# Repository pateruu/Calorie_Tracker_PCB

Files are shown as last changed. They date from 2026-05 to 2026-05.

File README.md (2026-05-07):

# Calorie Tracker PCB

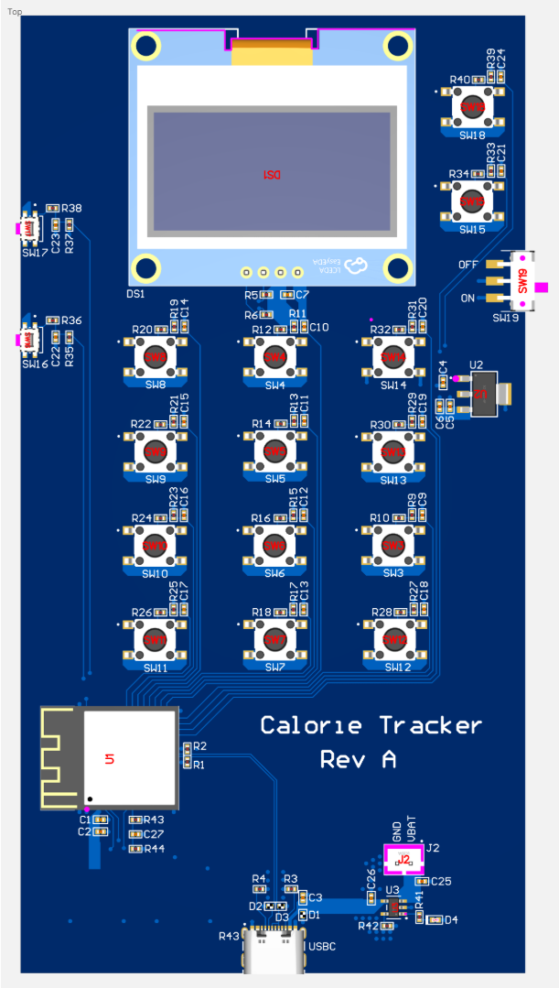
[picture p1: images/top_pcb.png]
Top PCB


A compact embedded handheld device built around an **ESP32-S3**, featuring an **OLED display**, **button-based numeric input**, **USB-C power/programming**, **battery charging**, and onboard **3.3V regulation** to track cumulative calorie intake.

This project focuses on the **hardware design** of a portable calorie tracker, including schematic capture, PCB layout, power architecture, button input circuitry, and manufacturing files. Firmware bring-up is being developed separately using an ESP32-based prototype platform before full hardware fabrication.

---

## Overview

The goal of this project was to design a custom handheld PCB that could serve as a dedicated calorie tracking device. The board is centered around an **ESP32-S3** and uses a **OLED display** for UI output, along with a set of **physical buttons** for entering values and navigating the interface.

The design includes:

- **ESP32-S3** microcontroller
- **OLED display** interface
- **button-based input** with debounce filtering
- **USB-C** for power and programming
- **battery charging / battery connector**
- **VBAT to 3.3V regulation**
- **persistent storage support through the MCU**
- custom schematic, PCB layout, BOM, pick-and-place, and fabrication files

---

## Key Features

- Custom **ESP32-S3 handheld PCB**
- **OLED display** for calorie total and UI feedback
- **Button-based numeric input** and menu navigation
- **USB-C power and programming**
- **Battery charging and power-path support**
- Onboard **3.3V regulator**
- Hardware debounce on user input buttons
- Organized design files for manufacturing and documentation

---

## Hardware Highlights

### Main Components
- **ESP32-S3** microcontroller
- **1.54" OLED display** interface
- **USB-C connector** with protection and CC resistors
- **Battery charging IC**
- **VBAT to 3.3V regulator**
- Tactile buttons for:
  - numeric entry
  - menu/navigation
  - reset
  - boot/programming access

### Design Considerations
- Routed dedicated **power rails** for **VBAT**, **VSYS**, and **+3V3_REG**
- Added local **decoupling capacitors** near critical ICs
- Implemented **button debounce/filter networks**
- Used **ground stitching vias** in USB and power areas
- Kept USB protection and power components grouped tightly near the connector

---

## Current Status

### Completed
- Schematic capture
- PCB placement and routing
- Power architecture
- USB-C and protection layout
- OLED and button interface design
- BOM / CPL / manufacturing file generation
- LTspice simulation for button debounce validation

### In Progress
- Firmware prototyping on ESP32 development hardware
- UI / input logic validation
- Pre-fabrication review and cleanup

### Planned
- Fabrication / assembly
- Bring-up and validation on final custom board
- Enclosure integration
- Final user interface refinement

---

## Repository Structure

```text
Calorie_Tracker_PCB/
├── docs/
├── firmware/
├── hardware/
│   ├── 3d_model/
│   ├── bom/
│   ├── drc/
│   ├── gerber/
│   ├── nc_drill/
│   ├── pcb/
│   ├── pick_place/
│   └── schematic/
├── images/
├── simulations/
│   └── ltspice/
├── LICENSE
└── README.md

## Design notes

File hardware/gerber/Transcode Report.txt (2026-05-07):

   ---- Transcoding 'C:\Users\Public\Documents\Altium\Calorie Tracker\Project Outputs for Calorie Tracker\Gerber\Calorie Tracker PCB.G1' ----   Wed May  6 06:54:53 2026

D56   --> D100
D57   --> D101
D64   --> D102
D65   --> D103
D67   --> D104
D68   --> D105
-----------------------------------------------------------------

   ---- Transcoding 'C:\Users\Public\Documents\Altium\Calorie Tracker\Project Outputs for Calorie Tracker\Gerber\Calorie Tracker PCB.GBL' ----   Wed May  6 06:54:53 2026

D25   --> D106
D56   --> D107
D57   --> D108
D64   --> D109
D65   --> D110
D66   --> D111
D67   --> D112
D68   --> D113
-----------------------------------------------------------------

   ---- Transcoding 'C:\Users\Public\Documents\Altium\Calorie Tracker\Project Outputs for Calorie Tracker\Gerber\Calorie Tracker PCB.GBP' ----   Wed May  6 06:54:53 2026

D25   --> D114
-----------------------------------------------------------------

   ---- Transcoding 'C:\Users\Public\Documents\Altium\Calorie Tracker\Project Outputs for Calorie Tracker\Gerber\Calorie Tracker PCB.GBS' ----   Wed May  6 06:54:53 2026

D53   --> D115
D54   --> D116
D55   --> D117
D56   --> D118
D57   --> D119
D58   --> D120
D59   --> D121
-----------------------------------------------------------------

   ---- Transcoding 'C:\Users\Public\Documents\Altium\Calorie Tracker\Project Outputs for Calorie Tracker\Gerber\Calorie Tracker PCB.GP1' ----   Wed May  6 06:54:53 2026

D73   --> D122
D74   --> D123
D75   --> D124
D76   --> D125
D77   --> D126
D78   --> D127
-----------------------------------------------------------------

   ---- Transcoding 'C:\Users\Public\Documents\Altium\Calorie Tracker\Project Outputs for Calorie Tracker\Gerber\Calorie Tracker PCB.GTL' ----   Wed May  6 06:54:53 2026

D18   --> D128
D19   --> D129
D20   --> D130
D22   --> D131
D23   --> D132
D24   --> D133
D25   --> D134
D27   --> D135
D28   --> D136
D29   --> D137
D30   --> D138
D31   --> D139
D32   --> D140
D33   --> D141
D34   --> D142
D35   --> D143
D36   --> D144
D56   --> D145
D57   --> D146
D64   --> D147
D65   --> D148
D66   --> D149
D67   --> D150
D68   --> D151
-----------------------------------------------------------------

   ---- Transcoding 'C:\Users\Public\Documents\Altium\Calorie Tracker\Project Outputs for Calorie Tracker\Gerber\Calorie Tracker PCB.GTP' ----   Wed May  6 06:54:53 2026

D18   --> D152
D19   --> D153
D20   --> D154
D22   --> D155
D23   --> D156
D24   --> D157
D25   --> D158
D27   --> D159
D28   --> D160
D29   --> D161
D30   --> D162
D31   --> D163
D32   --> D164
D33   --> D165
D34   --> D166
D35   --> D167
D36   --> D168
-----------------------------------------------------------------

   ---- Transcoding 'C:\Users\Public\Documents\Altium\Calorie Tracker\Project Outputs for Calorie Tracker\Gerber\Calorie Tracker PCB.GTS' ----   Wed May  6 06:54:53 2026

D20   --> D169
D28   --> D170
D31   --> D171
D32   --> D172
D38   --> D173
D39   --> D174
D40   --> D175
D41   --> D176
D42   --> D177
D43   --> D178
D45   --> D179
D46   --> D180
D47   --> D181
D48   --> D182
D49   --> D183
D50   --> D184
D51   --> D185
D52   --> D186
D53   --> D187
D54   --> D188
D55   --> D189
D56   --> D190
D57   --> D191
D58   --> D192
D59   --> D193
-----------------------------------------------------------------

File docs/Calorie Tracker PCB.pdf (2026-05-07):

# Calorie Tracker PCB Project Plan

Planning document for turning my current ESP32-S3 board into a compact handheld embedded device.
Project | Battery-powered handheld calorie tracker with OLED display, numeric button input, persistent storage, and custom PCB.
Goal | Reuse my ESP32-S3 design, remove unnecessary dev-board style circuitry, and build a clean enclosure-ready PCB.

## 1. Project Summary

My plan is to take the ESP32-S3 schematic I already built and reduce it into a focused product-style board instead of a general-purpose development board. The final device will let a user enter calorie values with buttons, view the running total on a small OLED screen, and keep the saved total even after power is removed.

## 2. Recommended Project Scope

- Use an ESP32-S3 module as the main controller.
- Use a 128×64 I2C OLED for the display.
- Provide button input for digits 0–9 and at least Enter / Clear / Reset.
- Store the running calorie total in non-volatile memory so data survives power-off.
- Keep one USB-C port for programming and wired power.
- Use a 3.3 V power rail for the ESP32-S3 and display.
- Lay out the board for a compact handheld enclosure.

## 3. High-Level System Architecture

Input | Controller | Output / Storage | Power
Buttons or keypad 0–9, Enter, Reset | ESP32-S3-MINI | 128×64 OLED NVS or external FRAM / EEPROM | USB-C 5 V input 3.3 V regulator LiPo battery

## 4. Components Needed (High-Level BOM)

Block | Main Item | Notes | Need?
MCU | ESP32-S3-MINI module | Main processor; reuse current design base | Yes
Display | 128×64 OLED, I2C | Small display for totals and menus | Yes
User input | Tactile buttons / keypad | Digits 0–9 plus Enter, Clear | Yes
Reset / boot | Reset and boot buttons | Keep for programming and recovery | Yes
USB | Single USB-C connector | Use for power and programming | Yes
Power | 3.3 V regulator | Convert 5 V or battery input to 3.3 V | Yes
Protection | ESD / decoupling / bulk caps | Keep standard USB and power support parts | Yes
Storage | ESP32 NVS or external FRAM | NVS is simplest; FRAM is stronger on hardware story | Yes
Battery option | LiPo connector + charger or AAA | Recommended over coin cell if | Optional

holder | portable power is needed

## 7. New Hardware Blocks To Add

- OLED interface wiring: VCC, GND, SDA, SCL, and any required pull-ups if not already present.
- Button network: either individual GPIO buttons or a keypad matrix to reduce pin count.
- Persistent storage choice: use ESP32 non-volatile storage first; optionally add external FRAM.
- Optional battery block: battery connector, charger IC, power-path handling, and battery sense divider.
- Optional on/off switch or load switch for a more product-like feel.

## 8. Firmware Plan

Feature | Planned behavior
Startup | On boot, load saved total from non-volatile memory and show it on the OLED.
Input | User enters a number with buttons 0–9; Enter confirms and adds the value.
Clear / edit | Allow Clear or Backspace behavior before confirming entry.
Reset total | Dedicated reset action sets the total back to zero after confirmation.
Persistence | Save the updated total after each confirmed entry so power loss does not erase data.
Low power | Optional deep-sleep mode with wake on button press.

## 9. PCB Layout Notes

- Place the OLED and main input buttons to support a handheld front-face layout.
- Keep the ESP32-S3 antenna edge clear: no copper pour, metal, battery, or display hardware in the keep-out area.
- Keep the power path short and clean from USB-C input to regulator to 3.3 V rail.
- Place decoupling capacitors close to the ESP32-S3 power pins and regulator pins.
- Add test points for 5 V, 3.3 V, GND, reset, and any important debug lines.
Mechanical planning matters here. The board should be laid out with the enclosure in mind from the beginning so the switch, OLED opening, and button positions look intentional.

## 11. Best Stretch Goals

1. Battery support: Add rechargeable battery charging and monitoring.
2. Low-power mode: Implement deep sleep and measure active vs. sleep current.
3. Keypad matrix: Reduce GPIO usage and clean up the front panel.
4. Enclosure: Add a 3D-printed case and show the assembled device.

## 13. Suggested Build Phases

5. Phase 1 — Schematic cleanup: Remove extra dev-board blocks and keep only the final device architecture.
6. Phase 2 — Peripheral addition: Add OLED, buttons, storage choice, and optional battery block.

7. Phase 3 — Firmware bring-up: Display startup screen, read buttons, and save/load totals.
8. Phase 4 — PCB layout: Route a compact board with test points and antenna keep-out respected.
9. Phase 5 — Prototype validation: Flash firmware, verify power rail stability, and test storage retention.
10. Phase 6 — Product polish: Add enclosure, measure current, and capture final build photos.

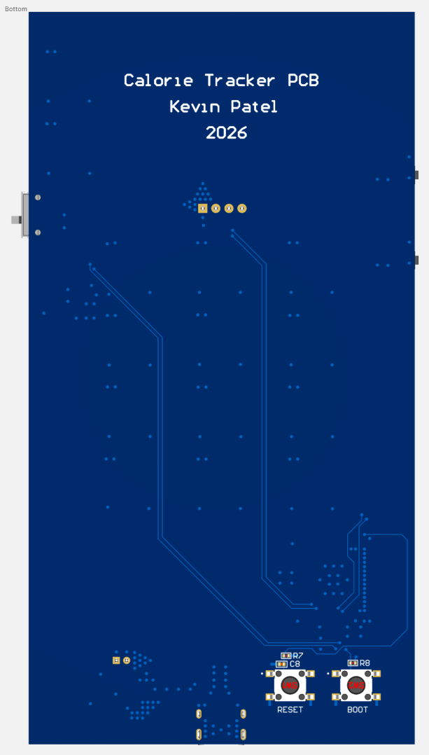
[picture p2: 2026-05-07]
images/bottom_pcb.png

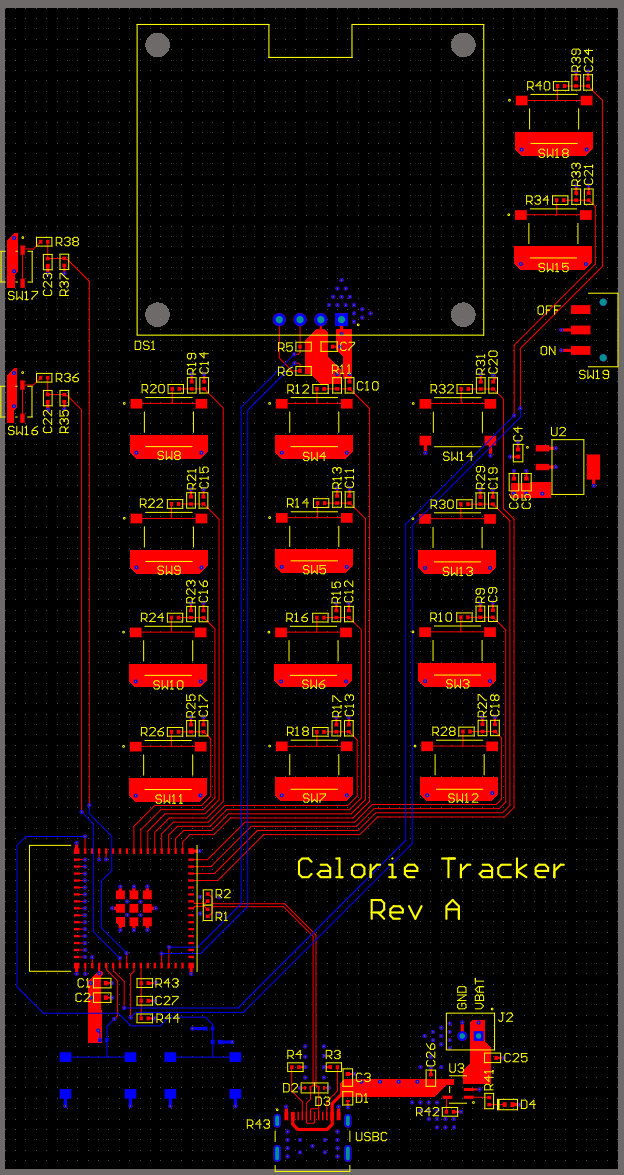
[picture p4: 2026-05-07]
images/top_and_bottom_pcb_altium.png

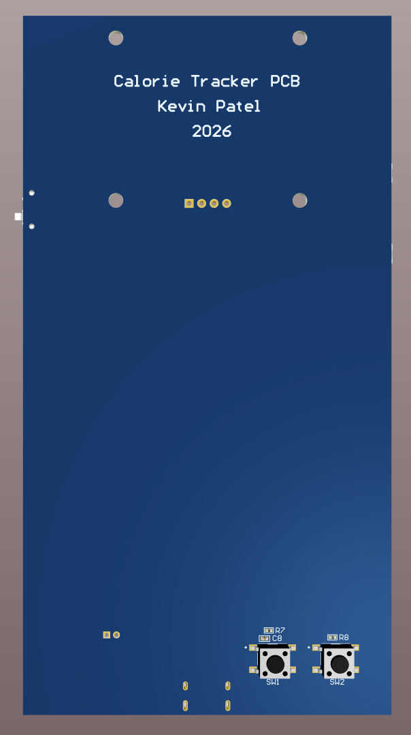
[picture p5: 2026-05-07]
images/bottom_pcb_altium.png

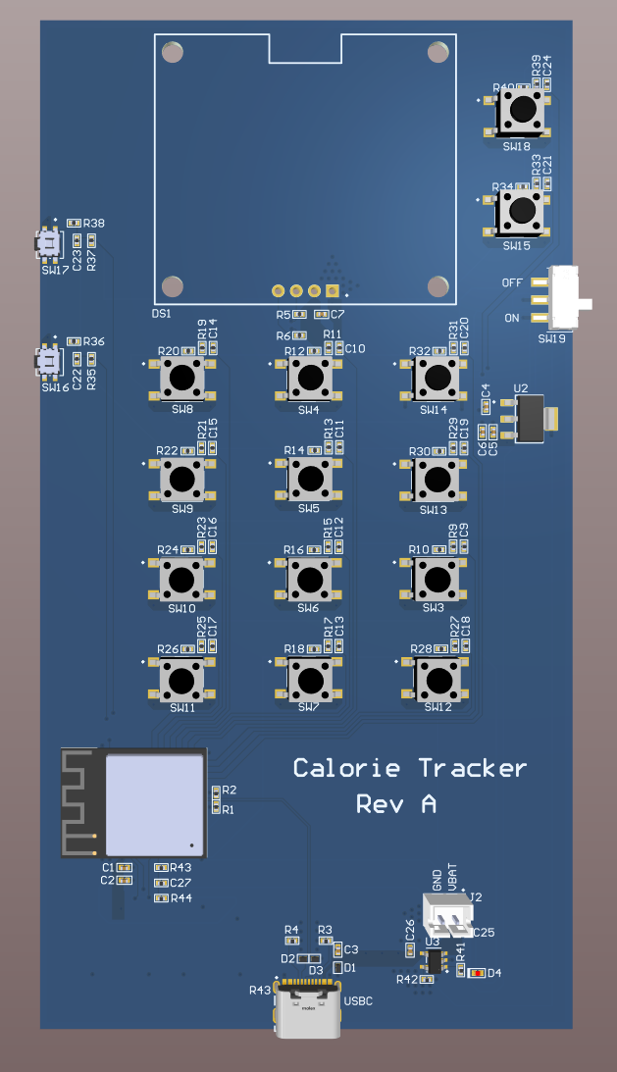
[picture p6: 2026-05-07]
images/top_pcb_altium.png

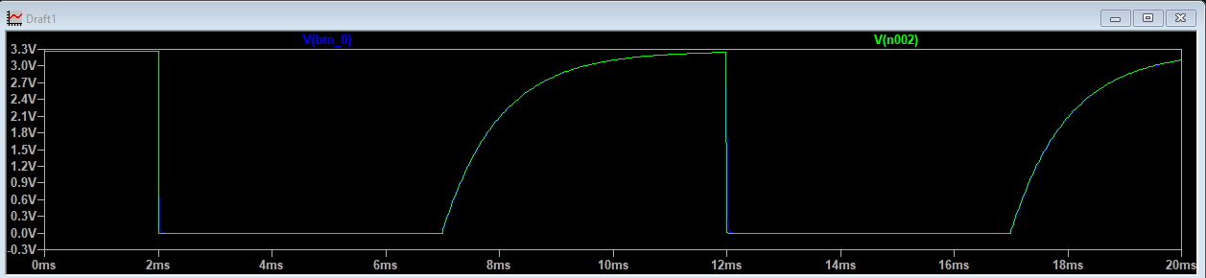
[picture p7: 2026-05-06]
simulations/ltspice/btn0_ltspice_plot.png

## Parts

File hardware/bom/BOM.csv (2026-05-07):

Name | Description | Designator | Footprint | LibRef | Quantity | LCSC Part Number | Manufacturer | Manufacturer Part Number | Supplier | Supplier Part Number
10uF, 10V | CAP CER 10UF 10V X5R 0402 | C1, C5, C6 | CAPC1005X65N | CL05A106MP6NUN8 | 3 | C3902158 | Samsung Electro-Mechanics | CL05A106MP6NUN8 | DigiKey | 1276-CL05A106MP6NUN8CT-ND
100nF, 50V | 0.1 µF ±10% 50V Ceramic Capacitor X7R 0402 (1005 Metric) | C2, C3 | CAPC1005X65N | CL05B104KB5NNNC | 2 | C960916 | Samsung Electro-Mechanics | CL05B104KB5NNNC | DigiKey | 1276-CL05B104KB5NNNCCT-ND
4u7, 16V | CAP CER 4.7UF 16V X5R 0402 | C4 | CAPC1005X65N | CL05A475MO5NUNC | 1 | C318563 | Samsung Electro-Mechanics | CL05A475MO5NUNC | DigiKey | 1276-6836-1-ND
0.1uF, 25V | CAP CER 0.1UF 25V X5R 0402 | C7 | 0402 Capacitor Footprint | CL05A104KA5NNNC | 1 | C100072 | Samsung Electro-Mechanics | CL05A104KA5NNNC | DigiKey | 1276-1043-1-ND
1uF, 35V | 1 µF ±10% 35V Ceramic Capacitor X5R 0402 (1005 Metric) | C8 | CAPC1005X65N | CL05A105KL5NRNC | 1 | C307413 | Samsung Electro-Mechanics | CL05A105KL5NRNC | DigiKey | 1276-6796-1-ND
100nF, 16V | CAP CER 0.1UF 16V X7R 0402 | C9, C10, C11, C12, C13, C14, C15, C16, C17, C18, C19, C20, C21, C22, C23, C24, C27 | 0402 Resistor Footprint | CC0402JRX7R7BB104 | 17 | C541464 | Yageo Group | CC0402JRX7R7BB104 | DigiKey | 311-1676-1-ND
4.7uF, 10V | CAP CER 4.7UF 10V X5R 0402 | C25, C26 | 0402 Capacitor Footprint | CL05A475MP5NRNC | 2 | C23733 | Samsung Electro-Mechanics | CL05A475MP5NRNC | DigiKey | 1276-1482-1-ND
AQ3045-01ETG | TVS DIODE 5.3VWM 12VC SOD882 | D1, D2, D3 | SOD882 | AQ3045-01ETG | 3 | C3710326 | Littelfuse | AQ3045-01ETG | DigiKey | F9321CT-ND
RED | LED RED 0402 SMD | D4 | LED0402R | VLMS1500-GS08 | 1 | C511370 | Vishay | VLMS1500-GS08 | DigiKey | VLMS1500-GS08CT-ND
HS154L03W2C01 | 1.54 128x64 SSD1309 chip I2C LCD, OLED, Graphic RoHS | DS1 | HS154L03W2C01 | HS154L03W2C01 | 1 | C7465999 | HS | HS154L03W2C01 | LCSC | HS154L03W2C01
217179-0001 | CONN RCP USB2.0 TYP C 24P SMD RA | J1 | FP-2171790001-MFG | 217179-0001 | 1 | C3197684 | Molex | 217179-0001 | DigiKey | 900-2171790001CT-ND
HDR_1X2_2MM | CONN HEADER VERT 2POS 2MM | J2 | B2B-PH-K-S | B2B-PH-K-S | 1 | C131337 | JST | B2B-PH-K-S | DigiKey | 455-1704-ND
22R | RES 22 OHM 1% 1/16W 0402 | R1, R2 | 0402 Resistor Footprint | RC0402FR-0722RL | 2 | C114765 | Yageo Group | RC0402FR-0722RL | DigiKey | 311-22.0LRCT-ND
5K1 | RES SMD 5.1K OHM 1% 1/16W 0402 | R3, R4 | RESC1005X37N | AC0402FR-075K1L | 2 | C144745 | Yageo Group | AC0402FR-075K1L | DigiKey | YAG3503CT-ND
4K7 | RES 4.7K OHM 1% 1/16W 0402 | R5, R6, R42 | RESC1005X37N | RC0402FR-074K7L | 3 | C105871 | Yageo Group | RC0402FR-074K7L | DigiKey | 311-4.7KLRCT-ND
10K | RES 10K OHM 1% 1/16W 0402 | R7, R8, R9, R11, R13, R15, R17, R19, R21, R23, R25, R27, R29, R31, R33, R35, R37, R39 | 0402 Resistor Footprint | RC0402FR-0710KL | 18 | C60490 | Yageo Group | RC0402FR-0710KL | DigiKey | 311-10.0KLRCT-ND
100R | RES 100 OHM 1% 1/16W 0402 | R10, R12, R14, R16, R18, R20, R22, R24, R26, R28, R30, R32, R34, R36, R38, R40 | 0402 Resistor Footprint | RC0402FR-07100RL | 16 | C106232 | Yageo Group | RC0402FR-07100RL | DigiKey | 311-100LRCT-ND
1K | RES 1K OHM 1% 1/16W 0402 | R41 | RESC1005X37N | RC0402FR-071KL | 1 | C106235 | Yageo Group | RC0402FR-071KL | DigiKey | 311-1.00KLRCT-ND
100K | RES 100K OHM 1% 1/16W 0402 | R43, R44 | 0402 Resistor Footprint | RC0402FR-07100KL | 2 | C60491 | Yageo Group | RC0402FR-07100KL | DigiKey | 311-100KLRCT-ND
PTS645SM43SMTR92LFS | SWITCH TACTILE SPST-NO 0.05A 12V | SW1, SW2, SW3, SW4, SW5, SW6, SW7, SW8, SW9, SW10, SW11, SW12, SW13, SW14, SW15, SW18 | FP-PTS645SM43SMTR92LFS-MFG | PTS645SM43SMTR92LFS | 16 | C221880 | C&K Components | PTS645SM43SMTR92LFS | DigiKey | CKN9112CT-ND
EVQ-P7A01P | SWITCH TACTILE SPST-NO 0.05A 12V | SW16, SW17 | EVQ_P7_PAN | EVQ-P7A01P | 2 | C79167 | Panasonic | EVQ-P7A01P | Avnet | EVQ-P7A01P
JS102011SAQN | SWITCH SLIDE SPDT 300MA 6V | SW19 | SW_JS102011SAQN | JS102011SAQN | 1 | C221660 | C&K Components | JS102011SAQN | DigiKey | 401-1999-6-ND
ESP32-S3-MINI-1-N8 | RF TXRX MOD BT WIFI PCB TH SMD | U1 | XCVR_ESP32-S3-MINI-1-N8 | ESP32-S3-MINI-1-N8 | 1 | C2913206 | Espressif Systems | ESP32-S3-MINI-1-N8 | DigiKey | 5407-ESP32-S3-MINI-1-N8CT-ND
TL1963A-33DCYR | IC REG LIN 3.3V 1.5A SOT-223-4 | U2 | DCY0004A_N | TL1963A-33DCYR | 1 | C181262 | Texas Instruments | TL1963A-33DCYR | DigiKey | 296-24897-1-ND
MCP73831T-2ACI/OT | IC BATT CNTL LI-ION 1CEL SOT23-5 | U3 | MCP73831T-2ACI/OT | MCP73831T-2ACI/OT | 1 | C424093 | Microchip | MCP73831T-2ACI/OT | DigiKey | MCP73831T-2ACI/OTCT-ND

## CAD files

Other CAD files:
hardware/pcb/Calorie Tracker Schematic.dwg

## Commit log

2026-05-06 added LTspice model for button debouncing
2026-05-07 added project files, images, docs, and simulations
    [BOM.csv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]
2026-05-07 added .dwg file for schematic
    [Calorie Tracker Schematic.dwg]
